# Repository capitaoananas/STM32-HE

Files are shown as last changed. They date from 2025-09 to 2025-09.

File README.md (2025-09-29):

# STM 32 HE

A silly [hall effect](https://en.wikipedia.org/wiki/Hall_effect) split keyboard with a built in [STM32F446RET6](https://lcsc.com/product-detail/Microcontrollers-MCU-MPU-SOC_ST-STM32F446RET6_C69336.html?s_z=n_STM32F446RET6) that runs on the [libhmk](https://github.com/peppapighs/libhmk) firmware!

Schematic             |  PCB
:-------------------------:|:-------------------------:
schematic  |  PCB

If you really want to crunch in on those errors check the [kicanvas](https://kicanvas.org/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) file

---

## Hardware:

- STM32F446RET6
- OH49E-S
- SN74LV4051A
- TC2030
- TYPE-C-31-M-12
- USBLC6-2SC6
- X322516MLB4SI

---

This project is still a WIP

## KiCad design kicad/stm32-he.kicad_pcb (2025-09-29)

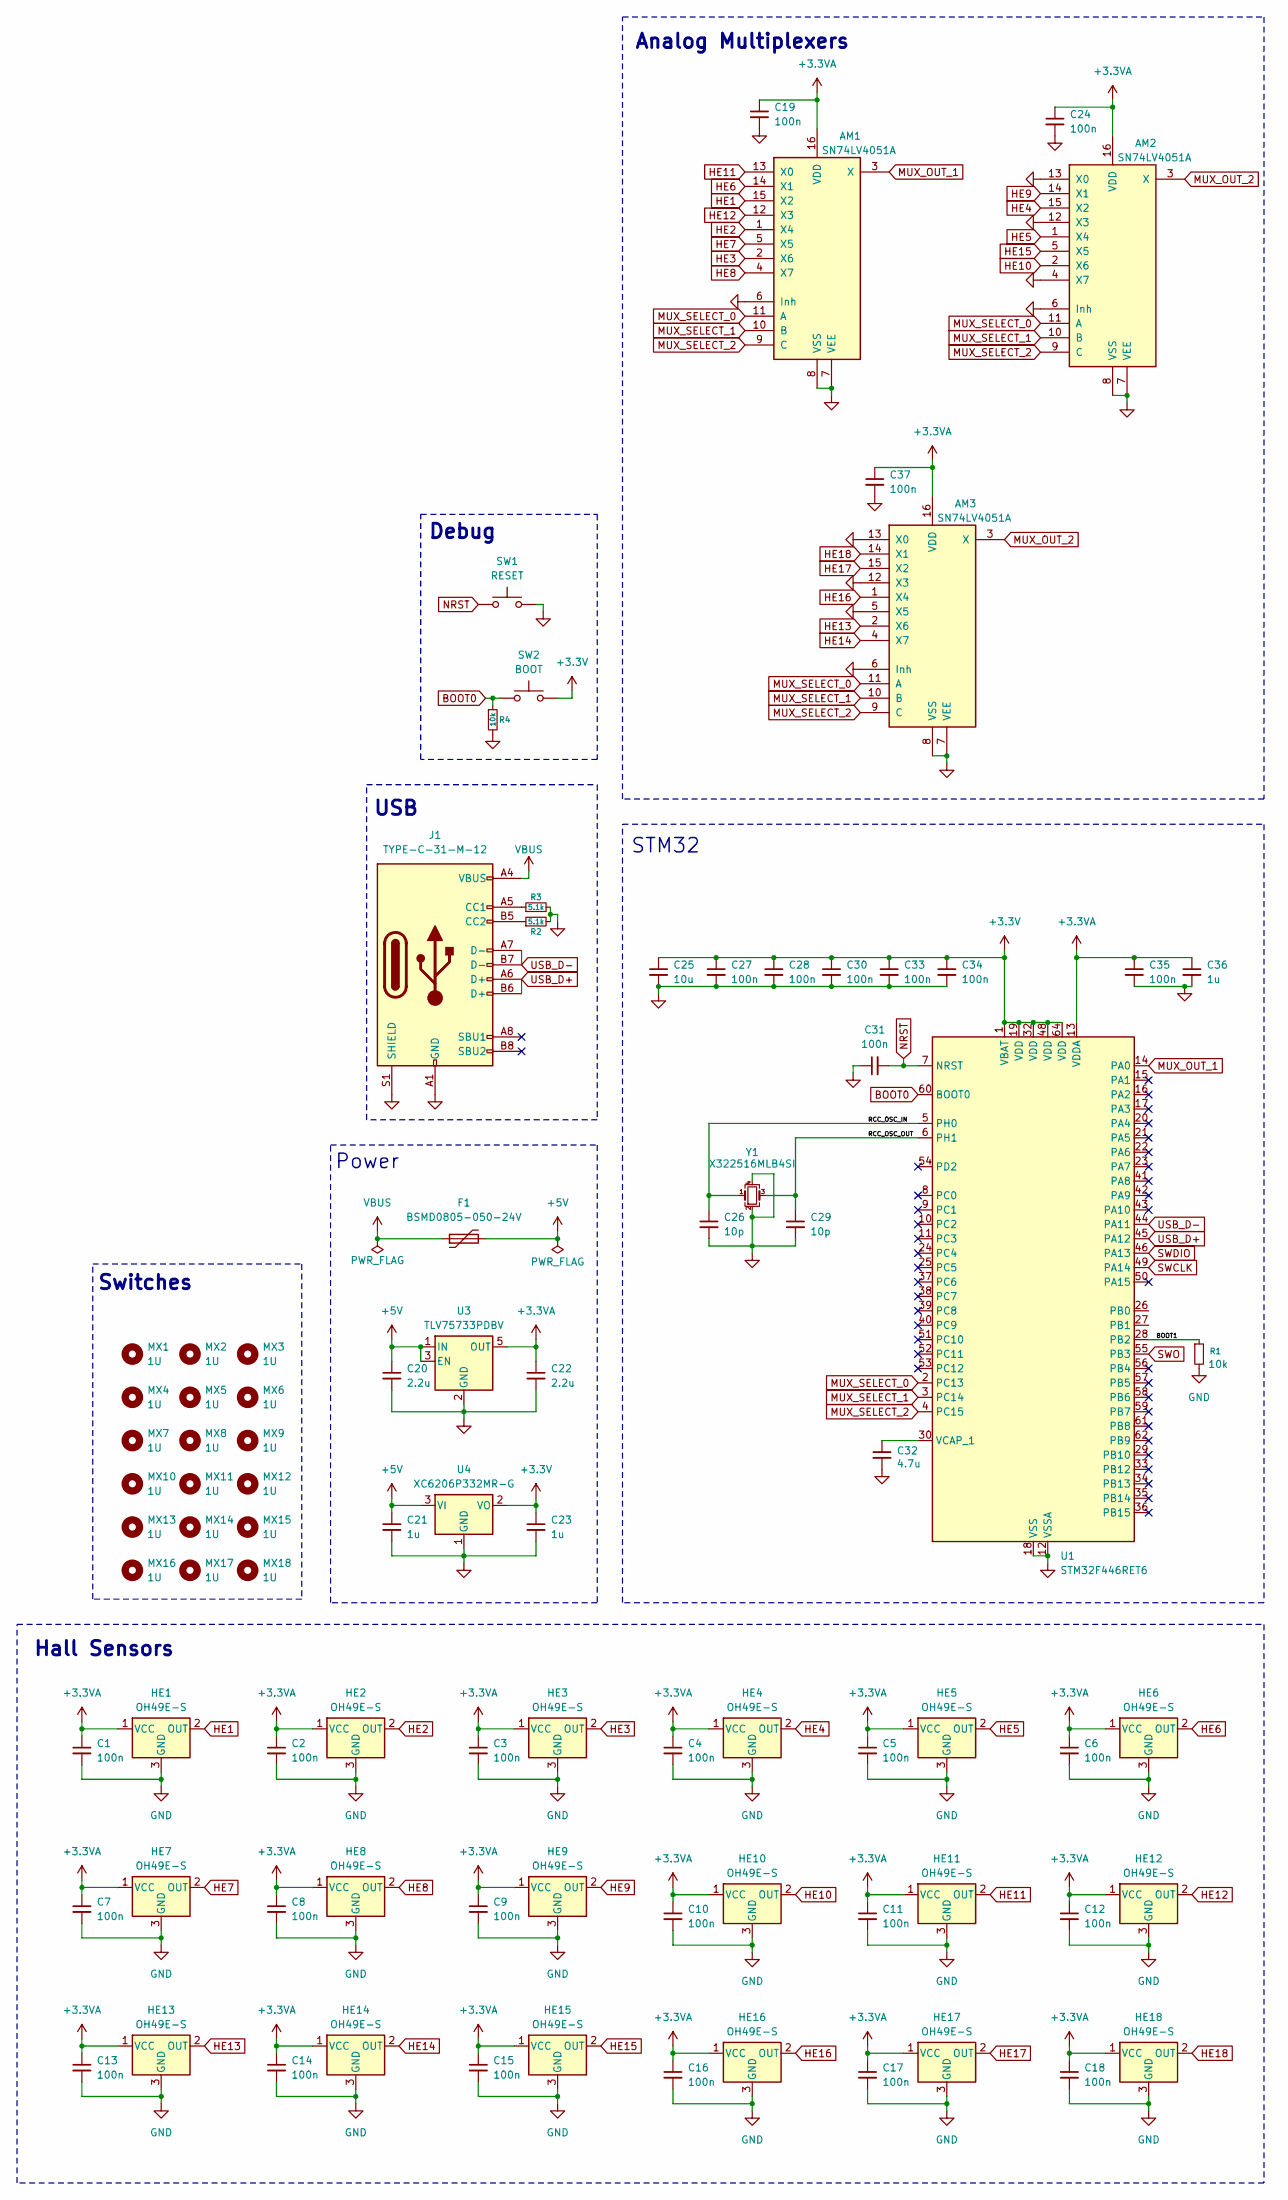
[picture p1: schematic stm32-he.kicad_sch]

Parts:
AM1, AM2, AM3: SN74LV4051A; TSSOP-16_4.4x5mm_P0.65mm
C1, C2, C3, C4, C5, C6, C7, C8, C9, C10, C11, C12, C13, C14, C15, C16, C17, C18, C19, C24, C27, C28, C30, C31, C33, C34, C35, C37: 100n; C_0402_1005Metric
C20, C22: 2.2u; C_0603_1608Metric
C21, C23, C36: 1u; C_0603_1608Metric
C25: 10u; C_0603_1608Metric
C26, C29: 10p; C_0402_1005Metric
C32: 4.7u; C_0603_1608Metric
F1: BSMD0805-050-24V; Fuse_0805_2012Metric
HE1, HE2, HE3, HE4, HE5, HE6, HE7, HE8, HE9, HE10, HE11, HE12, HE13, HE14, HE15, HE16, HE17, HE18: OH49E-S; SOT-23-3
J1: TYPE-C-31-M-12; USB_C_Receptacle_HRO_TYPE-C-31-M-12
MX1, MX2, MX3, MX4, MX5, MX6, MX7, MX8, MX9, MX10, MX11, MX12, MX13, MX14, MX15, MX16, MX17, MX18: 1U; MX-1U
R1, R4: 10k; R_0402_1005Metric
R2, R3: 5.1k; R_0402_1005Metric
SW1: RESET; SW_Push_1P1T_NO_CK_KMR2
SW2: BOOT; SW_Push_1P1T_NO_CK_KMR2
U1: STM32F446RET6; LQFP-64_10x10mm_P0.5mm
U3: TLV75733PDBV; SOT-23-5
U4: XC6206P332MR-G; SOT-23-3
Y1: X322516MLB4SI; Crystal_SMD_3225-4Pin_3.2x2.5mm

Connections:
+3.3V: C23.1, C25.1, C27.1, C28.1, C30.1, C33.1, C34.1, SW2.2, U1.1 (VBAT), U1.19 (VDD), U1.32 (VDD), U1.48 (VDD), U1.64 (VDD), U4.2 (VO)
+3.3VA: AM1.16 (VDD), AM2.16 (VDD), AM3.16 (VDD), C1.1, C2.1, C3.1, C4.1, C5.1, C6.1, C7.1, C8.1, C9.1, C10.1, C11.1, C12.1, C13.1, C14.1, C15.1, C16.1, C17.1, C18.1, C19.1, C22.1, C24.1, C35.1, C36.1, C37.1, HE1.1 (VCC), HE2.1 (VCC), HE3.1 (VCC), HE4.1 (VCC), HE5.1 (VCC), HE6.1 (VCC), HE7.1 (VCC), HE8.1 (VCC), HE9.1 (VCC), HE10.1 (VCC), HE11.1 (VCC), HE12.1 (VCC), HE13.1 (VCC), HE14.1 (VCC), HE15.1 (VCC), HE16.1 (VCC), HE17.1 (VCC), HE18.1 (VCC), U1.13 (VDDA), U3.5 (OUT)
+5V: C20.1, C21.1, F1.2, U3.1 (IN), U3.3 (EN), U4.3 (VI)
/BOOT1: R1.1, U1.28 (PB2)
/RCC_OSC_IN: C26.1, U1.5 (PH0), Y1.1
/RCC_OSC_OUT: C29.1, U1.6 (PH1), Y1.3
BOOT0: R4.1, SW2.1, U1.60 (BOOT0)
GND: AM1.6 (Inh), AM1.7 (VEE), AM1.8 (VSS), AM2.4 (X7), AM2.6 (Inh), AM2.7 (VEE), AM2.8 (VSS), AM2.12 (X3), AM2.13 (X0), AM3.5 (X5), AM3.6 (Inh), AM3.7 (VEE), AM3.8 (VSS), AM3.12 (X3), AM3.13 (X0), C1.2, C2.2, C3.2, C4.2, C5.2, C6.2, C7.2, C8.2, C9.2, C10.2, C11.2, C12.2, C13.2, C14.2, C15.2, C16.2, C17.2, C18.2, C19.2, C20.2, C21.2, C22.2, C23.2, C24.2, C25.2, C26.2, C27.2, C28.2, C29.2, C30.2, C31.1, C32.2, C33.2, C34.2, C35.2, C36.2, C37.2, HE1.3 (GND), HE2.3 (GND), HE3.3 (GND), HE4.3 (GND), HE5.3 (GND), HE6.3 (GND), HE7.3 (GND), HE8.3 (GND), HE9.3 (GND), HE10.3 (GND), HE11.3 (GND), HE12.3 (GND), HE13.3 (GND), HE14.3 (GND), HE15.3 (GND), HE16.3 (GND), HE17.3 (GND), HE18.3 (GND), J1.A1 (GND), J1.A12 (GND), J1.B1 (GND), J1.B12 (GND), J1.S1 (SHIELD), R1.2, R2.2, R3.2, R4.2, SW1.2, U1.12 (VSSA), U1.18 (VSS), U1.31 (VSS), U1.47 (VSS), U1.63 (VSS), U3.2 (GND), U4.1 (GND), Y1.2, Y1.4
HE1: AM1.15 (X2), HE1.2 (OUT)
HE2: AM1.1 (X4), HE2.2 (OUT)
HE3: AM1.2 (X6), HE3.2 (OUT)
HE4: AM2.15 (X2), HE4.2 (OUT)
HE5: AM2.1 (X4), HE5.2 (OUT)
HE6: AM1.14 (X1), HE6.2 (OUT)
HE7: AM1.5 (X5), HE7.2 (OUT)
HE8: AM1.4 (X7), HE8.2 (OUT)
HE9: AM2.14 (X1), HE9.2 (OUT)
HE10: AM2.2 (X6), HE10.2 (OUT)
HE11: AM1.13 (X0), HE11.2 (OUT)
HE12: AM1.12 (X3), HE12.2 (OUT)
HE13: AM3.2 (X6), HE13.2 (OUT)
HE14: AM3.4 (X7), HE14.2 (OUT)
HE15: AM2.5 (X5), HE15.2 (OUT)
HE16: AM3.1 (X4), HE16.2 (OUT)
HE17: AM3.15 (X2), HE17.2 (OUT)
HE18: AM3.14 (X1), HE18.2 (OUT)
MUX_OUT_1: AM1.3 (X), U1.14 (PA0)
MUX_OUT_2: AM2.3 (X), AM3.3 (X)
MUX_SELECT_0: AM1.11 (A), AM2.11 (A), AM3.11 (A), U1.2 (PC13)
MUX_SELECT_1: AM1.10 (B), AM2.10 (B), AM3.10 (B), U1.3 (PC14)
MUX_SELECT_2: AM1.9 (C), AM2.9 (C), AM3.9 (C), U1.4 (PC15)
NRST: C31.2, SW1.1, U1.7 (NRST)
unnamed: J1.A5 (CC1), R3.1
unnamed: J1.B5 (CC2), R2.1
unnamed: C32.1, U1.30 (VCAP_1)
SWCLK: U1.49 (PA14)
SWDIO: U1.46 (PA13)
SWO: U1.55 (PB3)
USB_D+: J1.A6 (D+), J1.B6 (D+), U1.45 (PA12)
USB_D-: J1.A7 (D-), J1.B7 (D-), U1.44 (PA11)
VBUS: F1.1, J1.A4 (VBUS), J1.A9 (VBUS), J1.B4 (VBUS), J1.B9 (VBUS)

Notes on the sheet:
Analog Multiplexers
STM32
USB
Power
Switches
Hall Sensors
Debug

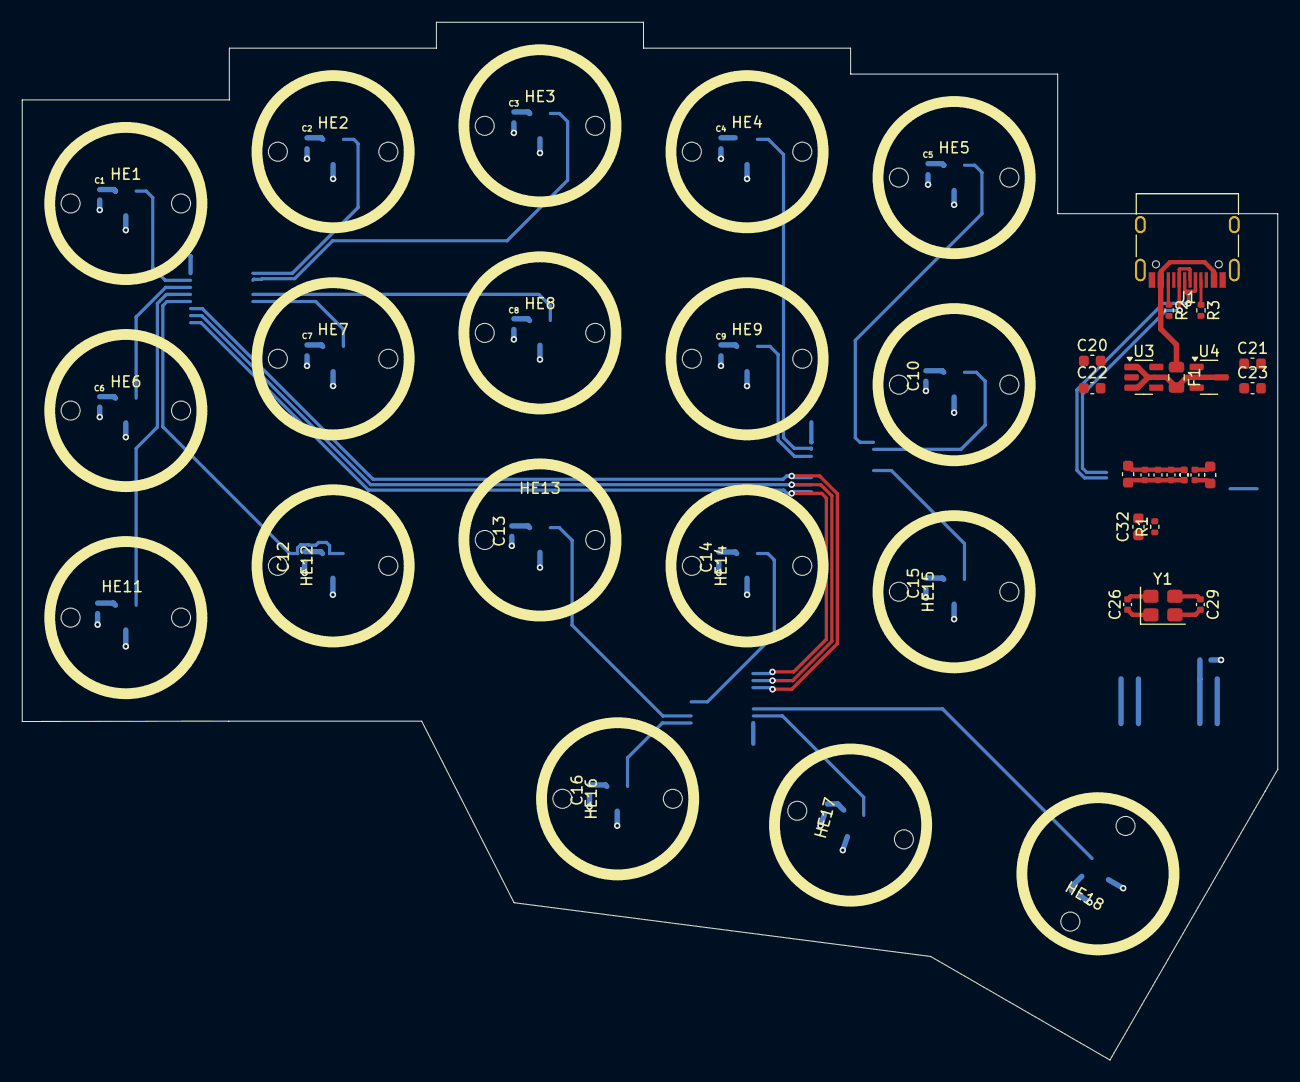
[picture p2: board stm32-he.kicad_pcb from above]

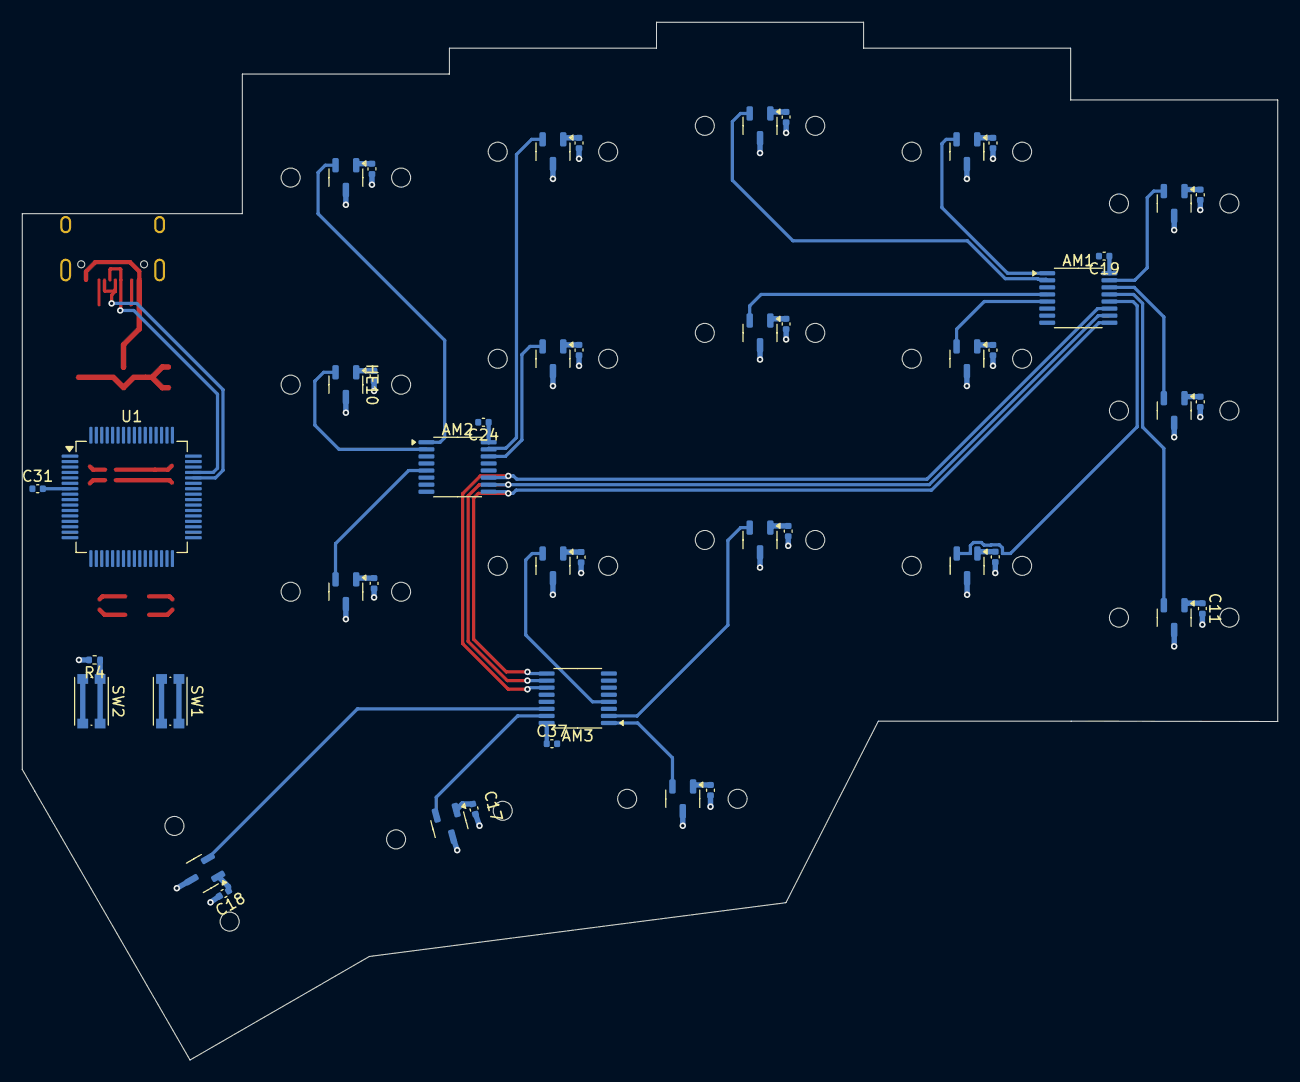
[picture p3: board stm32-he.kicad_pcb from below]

Board: 2 copper layers, 115.5 x 95.5 mm, 88 parts (47 on the bottom side), 38 nets.
